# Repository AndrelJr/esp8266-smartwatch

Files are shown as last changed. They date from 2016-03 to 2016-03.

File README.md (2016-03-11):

# ESP8266 Smartwatch
## Pictures / Videos
Features overview
Side view
On a wrist

#### YouTube Videos
* [Building the watch](https://www.youtube.com/watch?v=ve8lzYSVnGo)
* [Minetest controller](https://www.youtube.com/watch?v=W3ALEUs_7kA)
* [Compass test](https://www.youtube.com/watch?v=Mj3a6peVI30)

# Hardware
## Specifications
* ESP8266 with 32Mbit of flash memory
* MPU-9250 gyroscope, accelerometer with integrated AK8963 magnetometer
* RV-3029-C2 Real Time Clock
* FT232RQ for USB communication
* SSD1306 OLED Display, 128x64
* 3 Hardware Buttons
* MCP73831 LiPo charger
* 250mAh LiPo battery
* Dimensions: 35 * 39 * 11mm
* WiFi with chip antenna
* Vibration Motor

See `board/v1/README.md` for a detailed parts list.

# Software
The firmwares in `firmwares` use the [esp-open-sdk](https://github.com/pfalcon/esp-open-sdk). You may need to customize the `main.c` files to reflect your WiFi configuration. This is mainly a hardware project and not a software project, so the firmwares are primarily meant to be demos for the hardware features of the watch. Firmwares can be uploaded using [esptool](https://github.com/themadinventor/esptool) and debugging is possible with a serial port terminal like [espterm](https://github.com/Jeija/espterm).

# Attribution
* `libesphttpd` (used in the minetest firmware) was [written by Spritetm](https://github.com/Spritetm/libesphttpd) and contributors and is licensed under "THE BEER-WARE LICENSE".
* `httpclient.c` / `httpclient.h` (included in all firmwares) was [written by Caerbannog](https://github.com/Caerbannog/esphttpclient) and contributors and is licensed under "THE BEER-WARE LICENSE".
* `i2c_master.h` / `i2c_master.c` was written by Espressif Systems

# License
The hardware design (schematic, PCB design, footprints, ...) is licensed under a [Creative Commons Attribution-NonCommercial-ShareAlike 4.0 International License](http://creativecommons.org/licenses/by-nc-sa/4.0/) (CC-BY-NC-SA).

The firmware source code is licensed under the [MIT License](https://opensource.org/licenses/MIT).

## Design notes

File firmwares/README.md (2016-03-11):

## Notice
While it would certainly be nice to have one firmware that supports all the features of the watch, I haven't had the time yet to write that. Technically it is absolutely possible, since the watch has a 32Mbit flash chip which is certainly more than enough for all of the different firmwares here. Also, I haven't published a firmware yet that uses all of the power-saving features of the ESP8266. `wifitime` uses light sleep mode and wakes up every 1 second to update the screen, which makes the battery last for about 1 day. With deep sleep and less frequent updates, battery life can easily reach 2 days.

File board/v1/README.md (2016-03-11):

# ESP8266 Smartwatch Hardware V1
## Parts list
* 1x PCB
* 1x ESP8266EX WiFi SoC
* 1x FT232RQ USB to UART
* 1x MCP73831 LiPo charger
* 1x TLV70233 SOT-23 LDO (or compatible)
* 1x W25Q32BV 32Mbit flash
* 1x InvenSense MPU-9250 9-axis sensor
* 1x RV-3029-C2 RTC
* 1x 26MHz crystal 2.5x2mm
* 1x Rainsun AN9520 Chip Antenna
* 3x TS-015A / WS-TUS 434331045822 Buttons
* 1x muRata BLM21PG 600 EMI Suppression Filter
* 1x USB Micro B connector, SMD
* 1x EastRising SSD1306 OLED
* 1x 250mAh LiPo
* 1x Low power vibration motor
* 1x BC849 SOT-23 NPN transistor
* 6x 100nF 0603 Capacitor
* 3x 10nF 0603 Capacitor
* 2x 4.7µF 0603 Capacitor
* 1x 100µF 1206 Capacitor
* 1x 10µF 1206 Capacitor
* 1x 5.6pF 0402 Capacitor
* 2x 10pF 0402 Capacitor
* 5x 1µF 0603 Capacitor
* 1x 2.2µF 0603 Capacitor
* 3x 1N4148 SOD-323 Diode
* 2x 1K 0603 Resistor
* 1x 12K 0603 Resistor
* 1x 3.3K 0603 Resistor
* 1x 300 0603 Resistor
* 1x 200 0603 Resistor
* 1x 330K 0603 Resistor
* 1x 100K 0603 Resistor
* 4x 10K 0603 Resistor
* 1x 50 0603 Resistor
* 1x 390K 0603 Resistor

## Production files
See the `gerber` directory for original PCB production files. My PCBs were manufactured by Seeedstudio's PCB service.

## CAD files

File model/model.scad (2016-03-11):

// All units in millimeters
handle_height = 2;
handle_outer_width = 31;
handle_inner_width = 27;
handle_distance = 2;
handle_conn_width = 3;

pcb_width = 35;
pcb_height = 30;
pcb_thickness = 1;

oled_offset_top = 3;
oled_nodisp_height = 4;
oled_disp_height = 15;
oled_width = 26.5;
oled_thickness = 2;

battery_width = 31.5;
battery_height = 20;
battery_thickness = 6;
battery_offset_left = 0;
battery_offset_bottom = 8;

button_height = 5;
button_width = 3.5;
button_thickness = 2;

button_knob_thickness = 1.4;
button_knob_height = 2.6;
button_knob_width = 1;

button1_offset_top =  2.5;
button2_offset_top = 12.5;
button3_offset_top = 22.5;

usbconn_width = 6.5;
usbconn_height = 8;
usbconn_thickness = 2.5;
usbconn_width_pcb = 4.5;
usbconn_offset_bottom = 1;

pcb_drillhole_offset_bottom = 3.5;
pcb_drillhole_offset_right = 14;
pcb_drillhole_diameter = 2;

module pcb_handle() {
	linear_extrude(height = pcb_thickness)  polygon(points=[
		[-handle_inner_width / 2, pcb_height / 2 + handle_distance],
		[handle_inner_width / 2, pcb_height / 2 + handle_distance],
		[handle_outer_width / 2, pcb_height / 2 + handle_distance + handle_height],
		[-handle_outer_width / 2, pcb_height / 2 + handle_distance + handle_height]
	]);

	linear_extrude(height = pcb_thickness)  polygon(points=[
		[-pcb_width / 2, pcb_height / 2],
		[-pcb_width / 2 + handle_conn_width, pcb_height / 2],
		[-handle_inner_width / 2, pcb_height / 2 + handle_distance],
		[-handle_outer_width / 2, pcb_height / 2 + handle_distance + handle_height]
	]);

	linear_extrude(height = pcb_thickness)  polygon(points=[
		[pcb_width / 2, pcb_height / 2],
		[pcb_width / 2 - handle_conn_width, pcb_height / 2],
		[handle_inner_width / 2, pcb_height / 2 + handle_distance],
		[handle_outer_width / 2, pcb_height / 2 + handle_distance + handle_height]
	]);
}

module pcb_drillhole() {
	translate([pcb_width / 2 - pcb_drillhole_offset_right,
			-pcb_height / 2 + pcb_drillhole_offset_bottom, 0]) {
		cylinder(h = pcb_thickness * 2, d1 = pcb_drillhole_diameter, $fn = 90, center = true);
	}
}

module pcb() {
	color([0, 0.6, 0, 1]) {
		difference() {
			translate([-pcb_width / 2, -pcb_height / 2, -pcb_thickness / 2]) {
				cube(size = [pcb_width, pcb_height, pcb_thickness]);
			}
			pcb_drillhole();
		}

		translate([0, 0, -pcb_thickness / 2]) {
			// Upper handle
			pcb_handle();

			// Lower handle
			mirror([0, 1, 0]) pcb_handle();
		}
	}
}

module oled() {
	translate([-oled_width / 2, pcb_height / 2 - oled_offset_top, pcb_thickness / 2]) {
		// Controller area
		color([0.5, 0.5, 0.5, 0.5]) {
			translate([0, -oled_nodisp_height, 0])
				cube(size = [oled_width, oled_nodisp_height, oled_thickness]);
		}

		// Display area
		color([0, 0, 0, 0.8]) {
			translate([0, -oled_nodisp_height - oled_disp_height, 0])
				cube(size = [oled_width, oled_disp_height, oled_thickness]);
		}
	}
}

module battery() {
	translate([-pcb_width / 2, -pcb_height / 2, -pcb_thickness / 2]) {
		translate([battery_offset_left, battery_offset_bottom, -battery_thickness]) {
			color([0.5, 0.5, 0.5, 1.0])
			cube(size = [battery_width, battery_height, battery_thickness]);
		}
	}
}

module button(offsetx, offsety) {
	translate([offsetx, offsety, -button_thickness - pcb_thickness / 2]) {
		color([0.7, 0.7, 0.7, 1.0]) {
			cube(size = [button_width, button_height, button_thickness]);
		}
	
		translate([button_width, button_height / 2 - button_knob_height / 2, 0]) {
			color([0.2, 0.2, 0.2, 1.0]) {
				cube(size = [button_knob_width, button_knob_height, button_knob_thickness]);
			}
		}
	}
}

module buttons() {
	button(pcb_width / 2 - button_width, pcb_height / 2 - button_height -  button1_offset_top);
	button(pcb_width / 2 - button_width, pcb_height / 2 - button_height -  button2_offset_top);
	button(pcb_width / 2 - button_width, pcb_height / 2 - button_height -  button3_offset_top);
}

module usbconn(offsetx, offsety) {
	translate([offsetx, offsety, -pcb_thickness / 2 - usbconn_thickness]) {
		color([0.3, 0.3, 0.3, 1.0]) {
			cube([usbconn_width, usbconn_height, usbconn_thickness]);
		}
	}
}

module connectors() {
	usbconn(-pcb_width / 2 - usbconn_width + usbconn_width_pcb, -pcb_height / 2 + usbconn_offset_bottom);
}

module watch(centerx, centery) {
	translate([centerx, centery]) {
		pcb();
		oled();
		battery();
		buttons();
		connectors();
	}
}

watch(0, 0);

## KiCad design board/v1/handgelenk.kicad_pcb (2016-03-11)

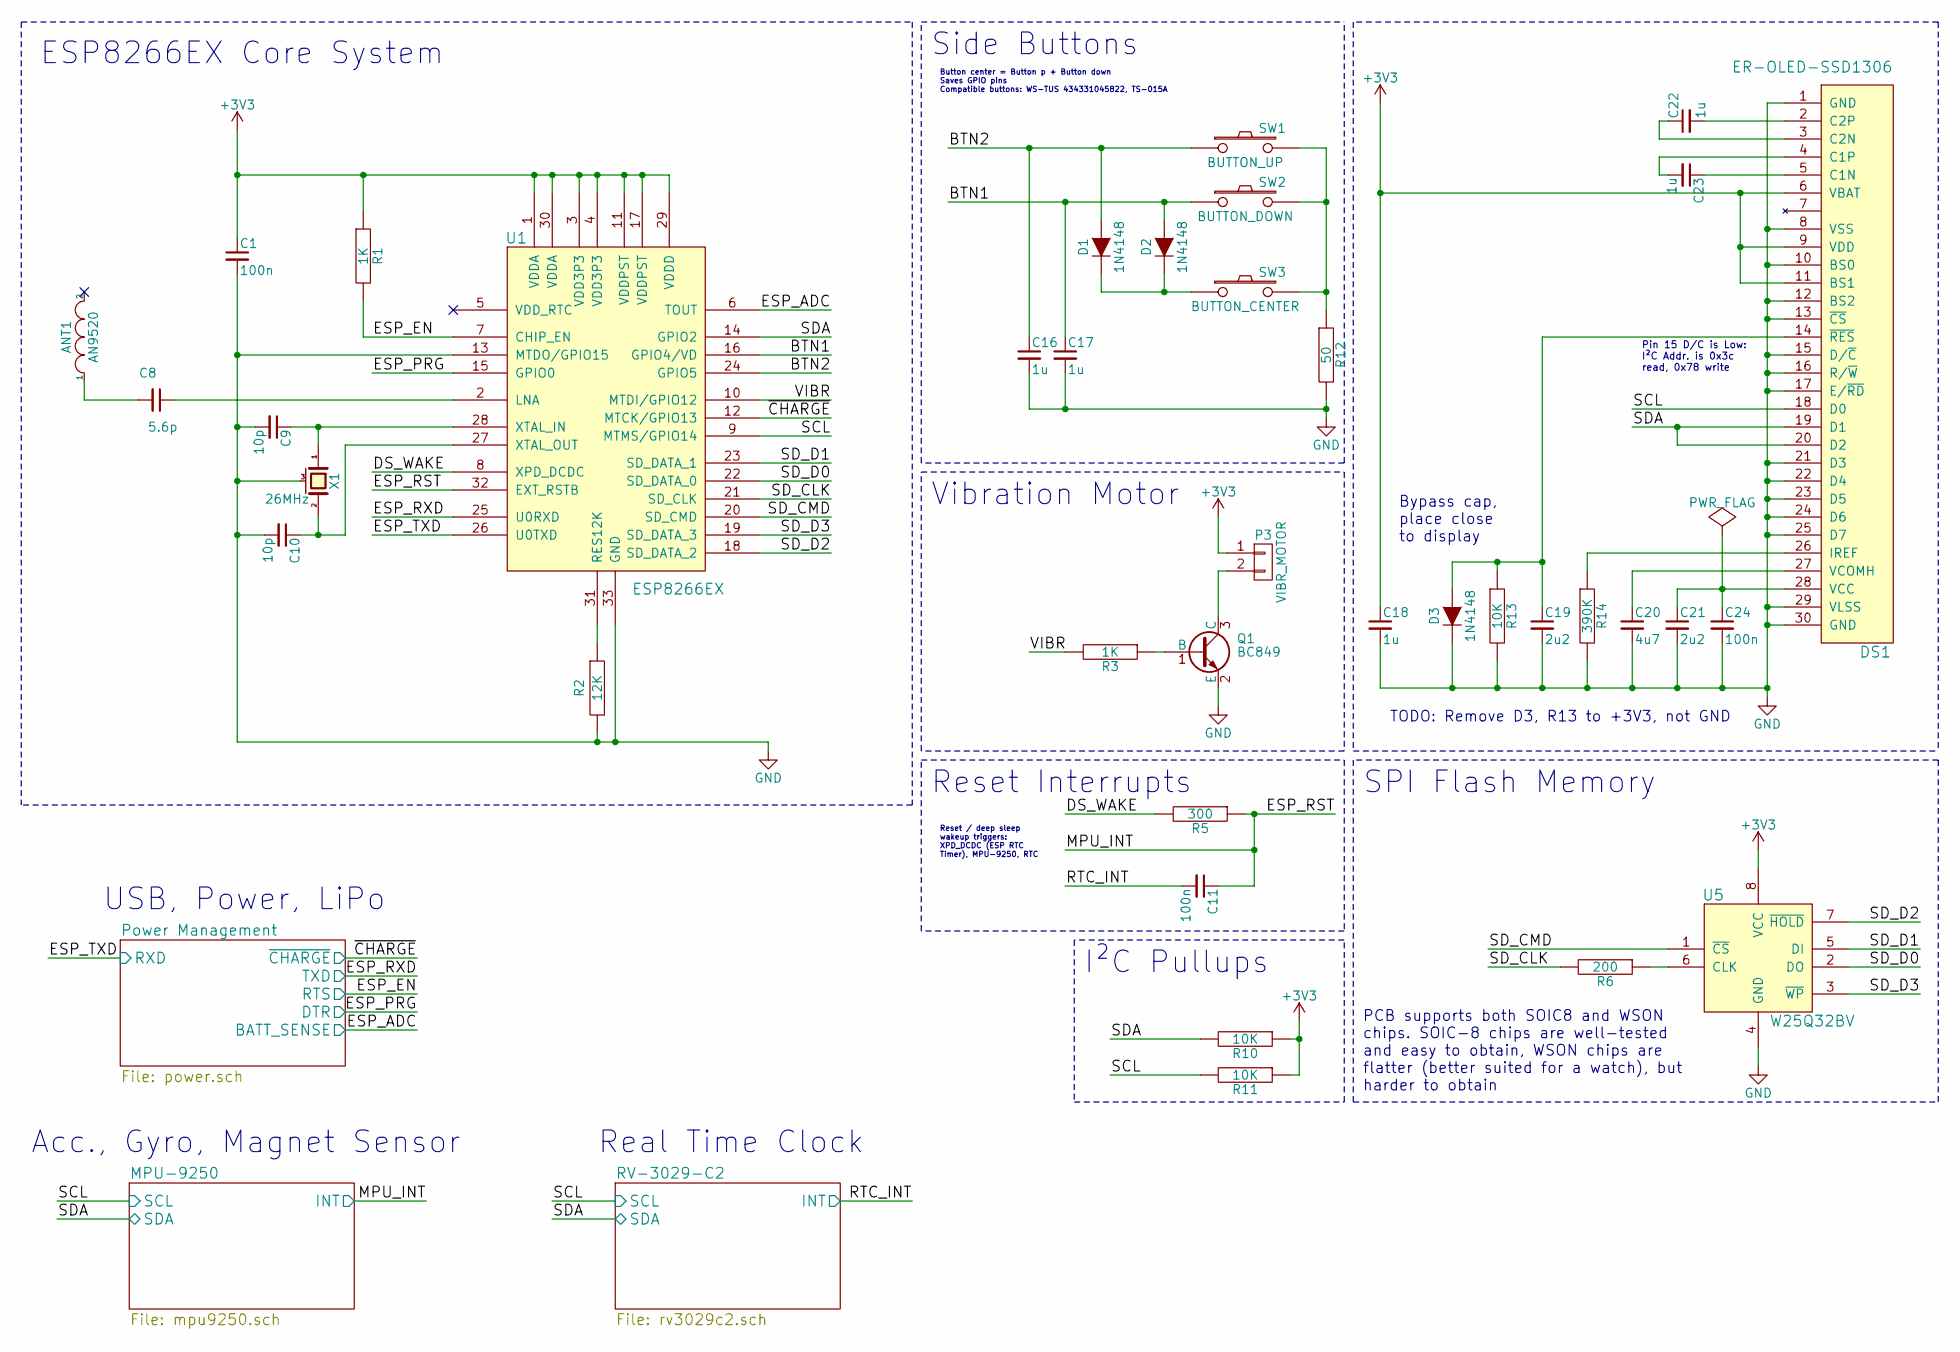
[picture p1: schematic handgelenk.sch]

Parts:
ANT1: AN9520; an9520
C1, C11, C24: 100n; C_0603
C8: 5.6p; C_0402
C9, C10: 10p; C_0402
C16, C17, C18, C22, C23: 1u; C_0603
C19, C21: 2u2; C_0603
C20: 4u7; C_0603
D1, D2, D3: 1N4148; SOD-323
DS1: ER-OLED-SSD1306; er-oled-ssd1306
P3: VIBR_MOTOR; Pin_Header_Straight_1x02
Q1: BC849; SOT-23
R1, R3: 1K; R_0603
R2: 12K; R_0603
R5: 300; R_0603
R6: 200; R_0603
R10, R11, R13: 10K; R_0603
R12: 50; R_0603
R14: 390K; R_0603
SW1: BUTTON_UP; ts015a
SW2: BUTTON_DOWN; ts015a
SW3: BUTTON_CENTER; ts015a
U1: ESP8266EX; QFN-32-1EP_5x5mm_Pitch0.5mm
U5: W25Q32BV; wson8_5x6
X1: 26MHz; crystal_2.5x2

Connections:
+3V3: C1.1, C18.1, DS1.6 (VBAT), DS1.9 (VDD), DS1.11 (BS1), P3.1, R1.1, R10.1, R11.1, U1.1 (VDDA), U1.3 (VDD3P3), U1.4 (VDD3P3), U1.11 (VDDPST), U1.17 (VDDPST), U1.29 (VDDD), U1.30 (VDDA), U5.8 (VCC); also elsewhere on the board
/BTN1: C17.1, D2.2 (A), SW2.1, U1.16 (GPIO4/VD)
/BTN2: C16.1, D1.2 (A), SW1.1, U1.24 (GPIO5)
/DS_WAKE: R5.2, U1.8 (XPD_DCDC)
/MPU-9250/INT: C11.1, R5.1, U1.32 (EXT_RSTB); also elsewhere on the board
/MPU-9250/SCL: DS1.18 (D0), R11.2, U1.9 (MTMS/GPIO14); also elsewhere on the board
/MPU-9250/SDA: DS1.19 (D1), DS1.20 (D2), R10.2, U1.14 (GPIO2); also elsewhere on the board
/Power Management/BATT_SENSE: U1.6 (TOUT); also elsewhere on the board
/Power Management/DTR: U1.15 (GPIO0); also elsewhere on the board
/Power Management/RTS: R1.2, U1.7 (CHIP_EN); also elsewhere on the board
/Power Management/RXD: U1.26 (U0TXD); also elsewhere on the board
/Power Management/TXD: U1.25 (U0RXD); also elsewhere on the board
/Power Management/~CHARGE: U1.12 (MTCK/GPIO13); also elsewhere on the board
/RV-3029-C2/INT: C11.2; also elsewhere on the board
/SD_CLK: R6.2, U1.21 (SD_CLK)
/SD_CMD: U1.20 (SD_CMD), U5.1 (~CS)
/SD_D0: U1.22 (SD_DATA_0), U5.2 (DO)
/SD_D1: U1.23 (SD_DATA_1), U5.5 (DI)
/SD_D2: U1.18 (SD_DATA_2), U5.7 (~HOLD)
/SD_D3: U1.19 (SD_DATA_3), U5.3 (~WP)
/VIBR: R3.2, U1.10 (MTDI/GPIO12)
GND: C1.2, C9.2, C10.2, C16.2, C17.2, C18.2, C19.2, C20.2, C21.2, C24.2, D3.1 (K), DS1.1 (GND), DS1.8 (VSS), DS1.10 (BS0), DS1.12 (BS2), DS1.13 (~CS), DS1.15 (D/~C), DS1.16 (R/~W), DS1.17 (E/~RD), DS1.21 (D3), DS1.22 (D4), DS1.23 (D5), DS1.24 (D6), DS1.25 (D7), DS1.29 (VLSS), DS1.30 (GND), Q1.2 (E), R2.2, R12.2, R13.2, R14.2, U1.13 (MTDO/GPIO15), U1.33 (GND), U5.4 (GND), X1.3 (case); also elsewhere on the board
unnamed: ANT1.1, C8.2
unnamed: C8.1, U1.2 (LNA)
unnamed: C9.1, U1.28 (XTAL_IN), X1.1
unnamed: C10.1, U1.27 (XTAL_OUT), X1.2
unnamed: C19.1, D3.2 (A), DS1.14 (~RES), R13.1
unnamed: C20.1, DS1.27 (VCOMH)
unnamed: C21.1, C24.1, DS1.28 (VCC)
unnamed: C22.1, DS1.3 (C2N)
unnamed: C22.2, DS1.2 (C2P)
unnamed: C23.1, DS1.5 (C1N)
unnamed: C23.2, DS1.4 (C1P)
unnamed: D1.1 (K), D2.1 (K), SW3.1
unnamed: DS1.26 (IREF), R14.1
unnamed: P3.2, Q1.3 (C)
unnamed: Q1.1 (B), R3.1
unnamed: R2.1, U1.31 (RES12K)
unnamed: R6.1, U5.6 (CLK)
unnamed: R12.1, SW1.2, SW2.2, SW3.2

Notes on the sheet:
Reset / deep sleep wakeup triggers: XPD_DCDC (ESP RTC Timer), MPU-9250, RTC
PCB supports both SOIC8 and WSON chips. SOIC-8 chips are well-tested and easy to obtain, WSON chips are flatter (better suited for a watch), but harder to obtain
SPI Flash Memory
Pin 15 D/C is Low: I²C Addr. is 0x3c read, 0x78 write
Bypass cap, place close to display
Button center = Button p + Button down Saves GPIO pins Compatible buttons: WS-TUS 434331045822, TS-015A
Side Buttons
Vibration Motor
ESP8266EX Core System
I²C Pullups
Reset Interrupts
Acc., Gyro, Magnet Sensor
Real Time Clock
USB, Power, LiPo
TODO: Remove D3, R13 to +3V3, not GND

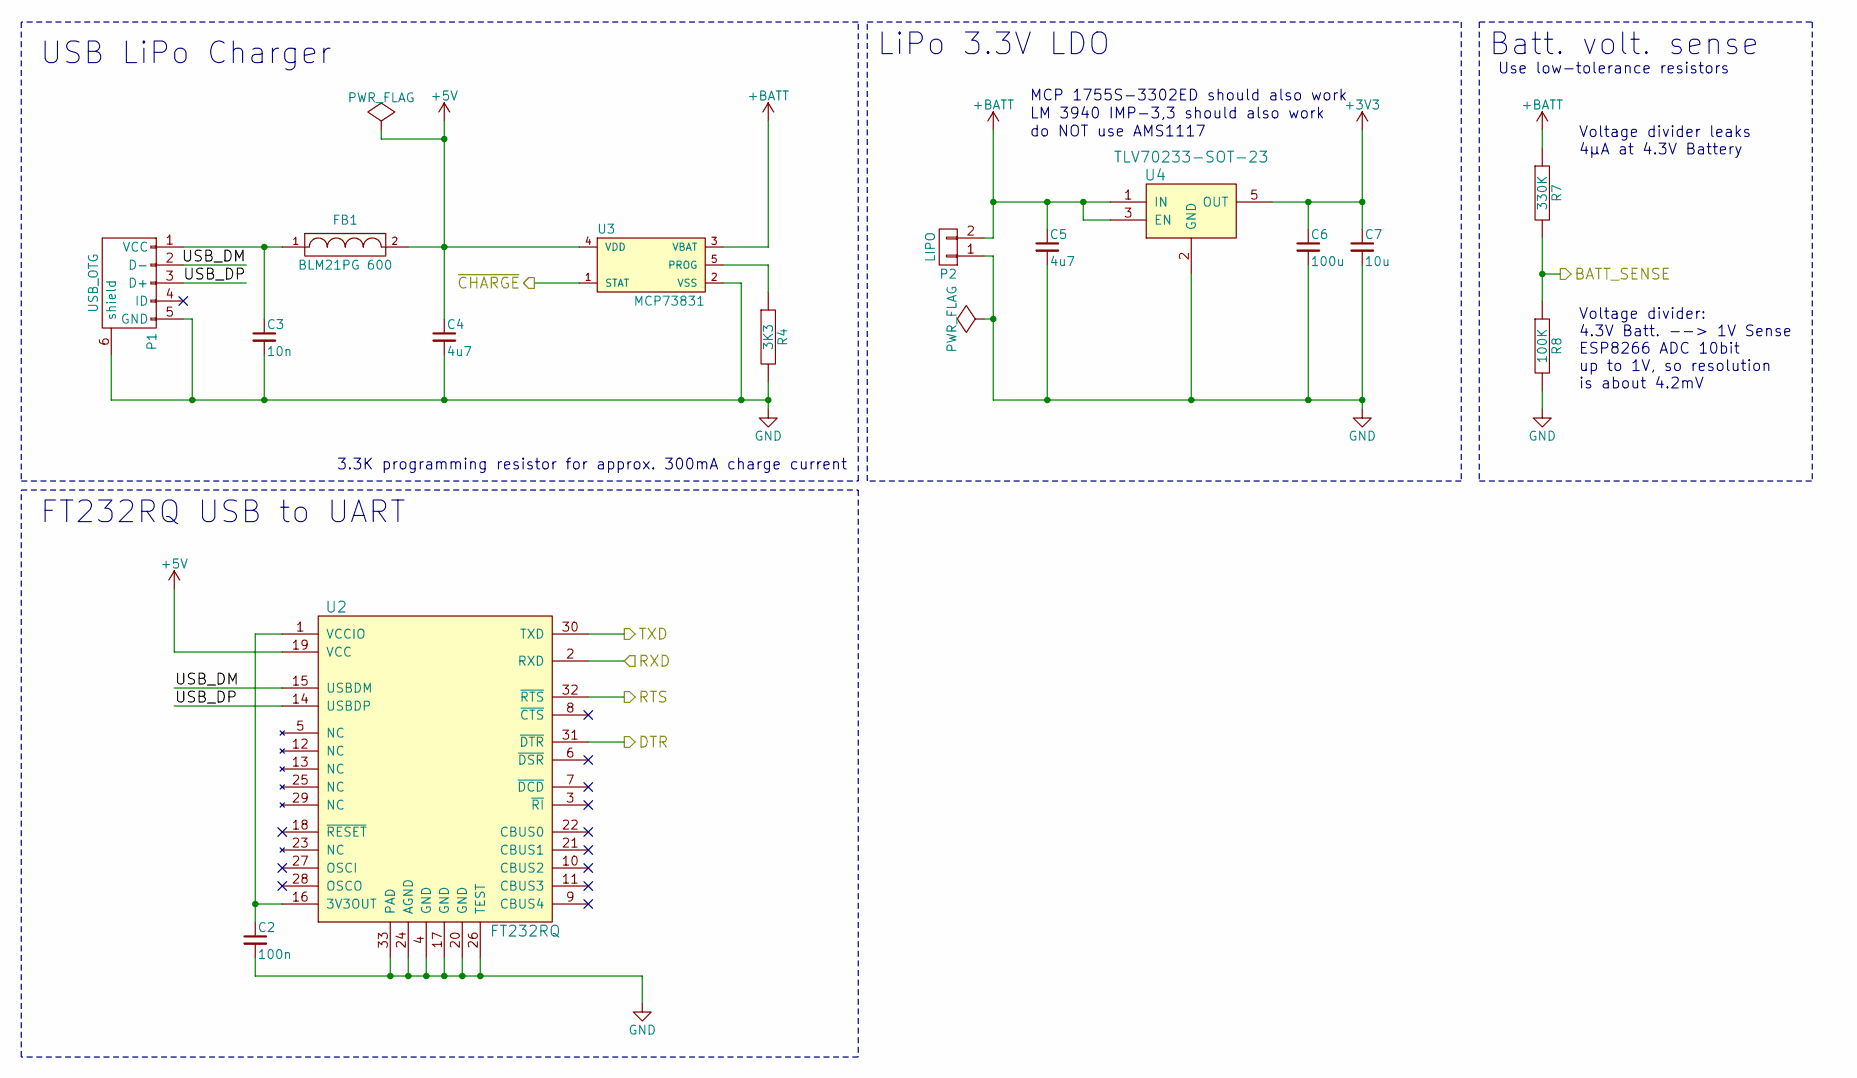
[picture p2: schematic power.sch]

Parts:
C2: 100n; C_0603
C3: 10n; C_0603
C4, C5: 4u7; C_0603
C6: 100u; C_1206
C7: 10u; C_0603
FB1: BLM21PG 600; C_0805
P1: USB_OTG; USB_Micro-B
P2: LIPO; Pin_Header_Straight_1x02
R4: 3K3; R_0603
R7: 330K; R_0603
R8: 100K; R_0603
U2: FT232RQ; QFN-32-1EP_5x5mm_Pitch0.5mm
U3: MCP73831; SOT-23-5
U4: TLV70233-SOT-23; SOT-23-5

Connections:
+3V3: C6.1, C7.1, U4.5 (OUT); also elsewhere on the board
+5V: C4.1, FB1.2, U2.19 (VCC), U3.4 (VDD)
+BATT: C5.1, P2.2, R7.1, U3.3 (VBAT), U4.1 (IN), U4.3 (EN)
/Power Management/BATT_SENSE: R7.2, R8.1; also elsewhere on the board
/Power Management/DTR: U2.31 (~DTR); also elsewhere on the board
/Power Management/RTS: U2.32 (~RTS); also elsewhere on the board
/Power Management/RXD: U2.2 (RXD); also elsewhere on the board
/Power Management/TXD: U2.30 (TXD); also elsewhere on the board
/Power Management/USB_DM: P1.2 (D-), U2.15 (USBDM)
/Power Management/USB_DP: P1.3 (D+), U2.14 (USBDP)
/Power Management/~CHARGE: U3.1 (STAT); also elsewhere on the board
GND: C2.2, C3.2, C4.2, C5.2, C6.2, C7.2, P1.5 (GND), P1.6 (shield), P2.1, R4.2, R8.2, U2.4 (GND), U2.17 (GND), U2.20 (GND), U2.24 (AGND), U2.26 (TEST), U2.33 (PAD), U3.2 (VSS), U4.2 (GND); also elsewhere on the board
unnamed: C2.1, U2.1 (VCCIO), U2.16 (3V3OUT)
unnamed: C3.1, FB1.1, P1.1 (VCC)
unnamed: R4.1, U3.5 (PROG)

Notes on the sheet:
do NOT use AMS1117
LM 3940 IMP-3,3 should also work
MCP 1755S-3302ED should also work
3.3K programming resistor for approx. 300mA charge current
LiPo 3.3V LDO
USB LiPo Charger
FT232RQ USB to UART
Batt. volt. sense
Use low-tolerance resistors
Voltage divider: 4.3V Batt. --> 1V Sense ESP8266 ADC 10bit up to 1V, so resolution is about 4.2mV
Voltage divider leaks 4µA at 4.3V Battery

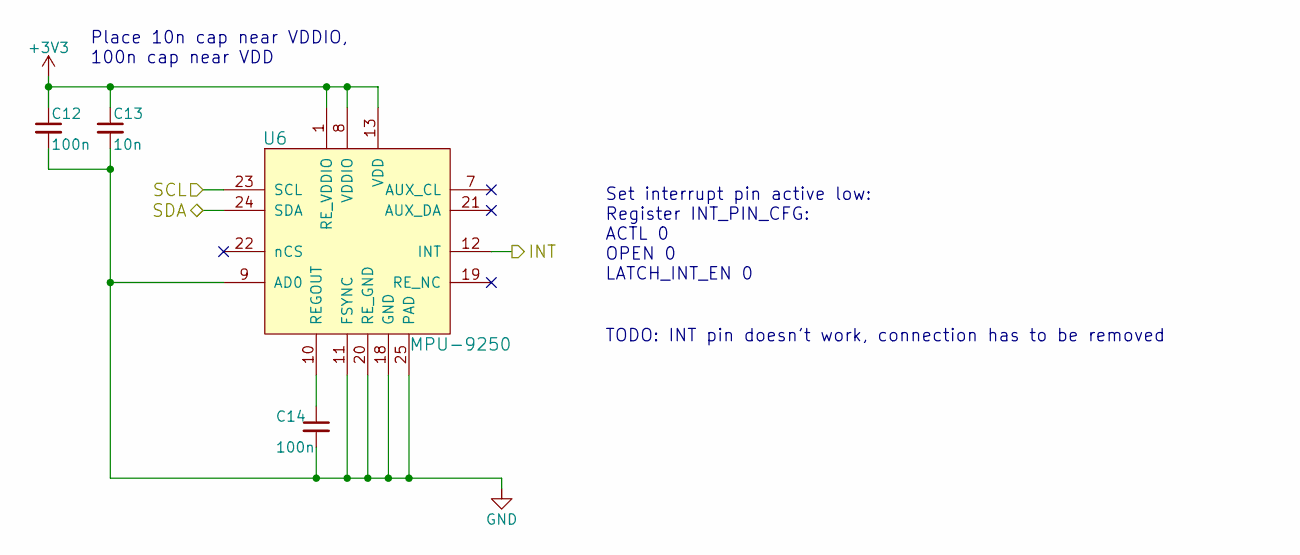
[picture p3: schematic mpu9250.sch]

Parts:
C12, C14: 100n; C_0603
C13: 10n; C_0603
U6: MPU-9250; QFN-24-1EP_3x3mm_Pitch0.4mm

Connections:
+3V3: C12.1, C13.1, U6.1 (RE_VDDIO), U6.8 (VDDIO), U6.13 (VDD); also elsewhere on the board
/MPU-9250/INT: U6.12 (INT); also elsewhere on the board
/MPU-9250/SCL: U6.23 (SCL); also elsewhere on the board
/MPU-9250/SDA: U6.24 (SDA); also elsewhere on the board
GND: C12.2, C13.2, C14.2, U6.9 (AD0), U6.11 (FSYNC), U6.18 (GND), U6.20 (RE_GND), U6.25 (PAD); also elsewhere on the board
unnamed: C14.1, U6.10 (REGOUT)

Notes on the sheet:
Place 10n cap near VDDIO, 100n cap near VDD
Set interrupt pin active low: Register INT_PIN_CFG: ACTL 0 OPEN 0 LATCH_INT_EN 0
TODO: INT pin doesn't work, connection has to be removed

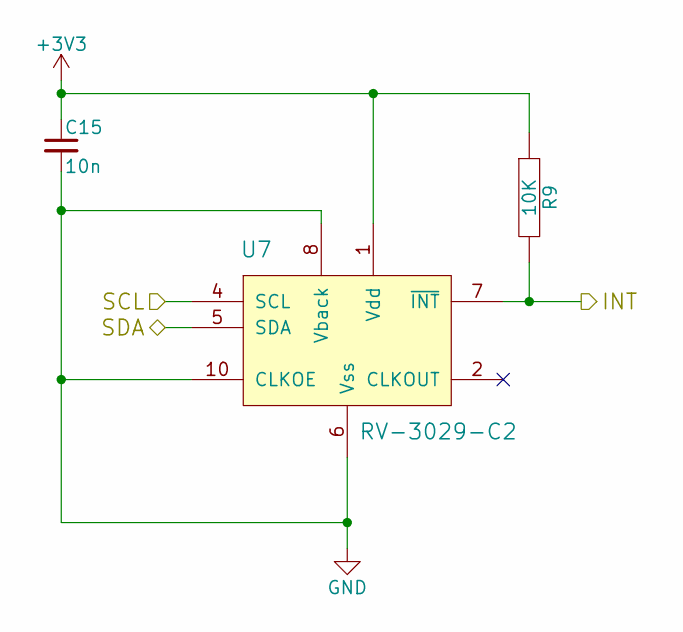
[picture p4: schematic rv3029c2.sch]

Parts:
C15: 10n; C_0603
R9: 10K; R_0603
U7: RV-3029-C2; rv3029

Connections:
+3V3: C15.1, R9.1, U7.1 (Vdd); also elsewhere on the board
/MPU-9250/SCL: U7.4 (SCL); also elsewhere on the board
/MPU-9250/SDA: U7.5 (SDA); also elsewhere on the board
/RV-3029-C2/INT: R9.2, U7.7 (~INT); also elsewhere on the board
GND: C15.2, U7.6 (Vss), U7.8 (Vback), U7.10 (CLKOE); also elsewhere on the board

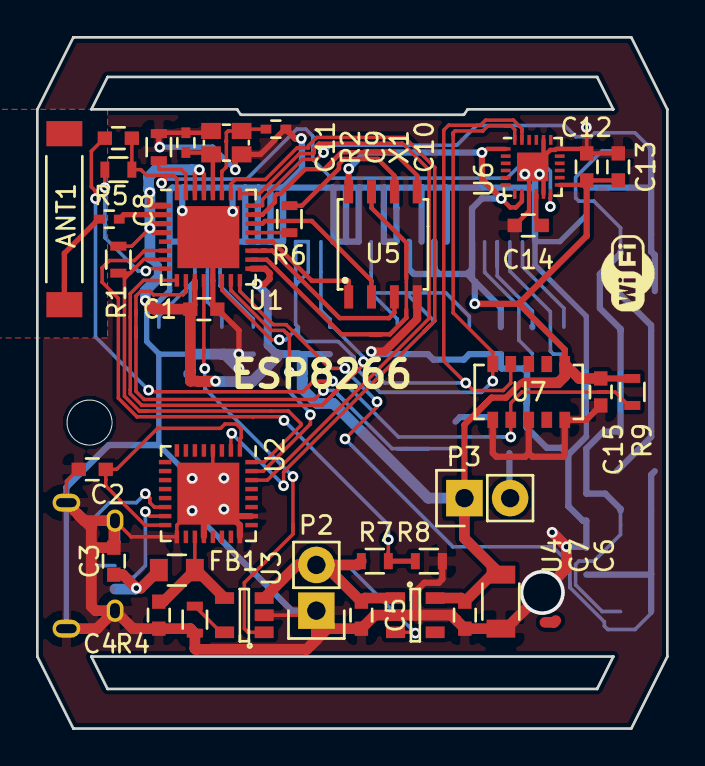
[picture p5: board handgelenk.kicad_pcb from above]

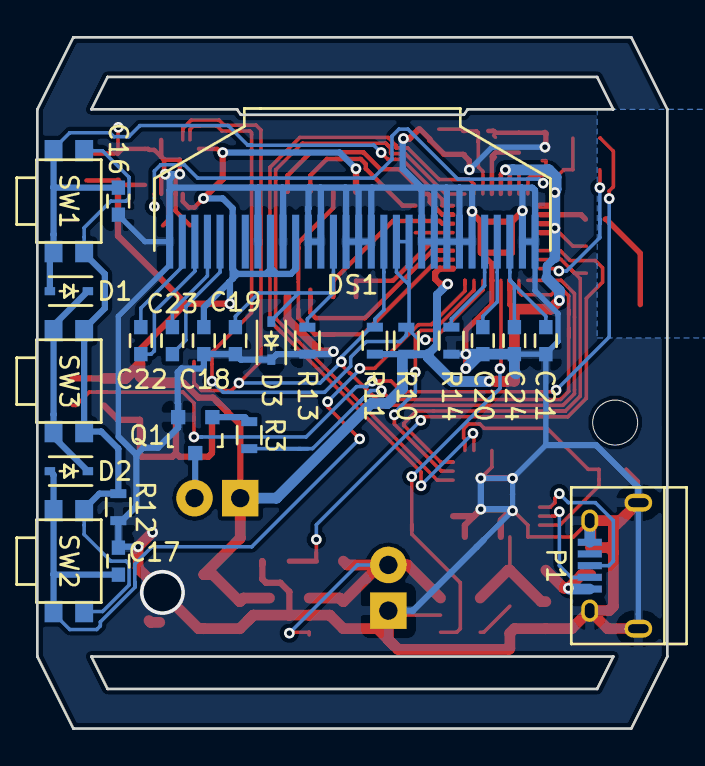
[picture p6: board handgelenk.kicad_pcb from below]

Board: 2 copper layers, 35.0 x 38.4 mm, 59 parts (24 on the bottom side), 48 nets.

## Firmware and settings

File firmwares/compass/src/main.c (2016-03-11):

// System
#include <user_interface.h>
#include <math.h>
#include <os_type.h>
#include <ets_sys.h>
#include <osapi.h>
#include <gpio.h>

// Configuration
#include "user_config.h"

// Project
#include "httpclient.h"
#include "i2c_master.h"
#include "buttons.h"
#include "mpu9250.h"
#include "ssd1306.h"
#include "rv3029.h"
#include "vector.h"
#include "util.h"

os_timer_t magnet_timer;
vec3f calib_bias;

#define COMPASS_CENTER_X 32
#define COMPASS_CENTER_Y 32
#define COMPASS_RADIUS 30
void ICACHE_FLASH_ATTR compass_draw(float angle) {
	float a;
	ssd1306_setpixel(COMPASS_CENTER_X, COMPASS_CENTER_Y, true);
	ssd1306_setpixel(COMPASS_CENTER_X + 1, COMPASS_CENTER_Y, true);
	ssd1306_setpixel(COMPASS_CENTER_X, COMPASS_CENTER_Y + 1, true);
	ssd1306_setpixel(COMPASS_CENTER_X - 1, COMPASS_CENTER_Y, true);
	ssd1306_setpixel(COMPASS_CENTER_X, COMPASS_CENTER_Y - 1, true);

	for (a = angle; a < angle + 2 * PI; a += PI / 8) {
		float startx =  ((a == angle) ? COMPASS_RADIUS - 15 : COMPASS_RADIUS - 5) * sin(a) + COMPASS_CENTER_X;
		float starty = -((a == angle) ? COMPASS_RADIUS - 15 : COMPASS_RADIUS - 5) * cos(a) + COMPASS_CENTER_Y;
		float endx =  COMPASS_RADIUS * sin(a) + COMPASS_CENTER_X;
		float endy = -COMPASS_RADIUS * cos(a) + COMPASS_CENTER_Y;
		if (a == angle)
			ssd1306_text_small(startx - 3 - (endx - startx) / 2, starty - 4 - (endy - starty) / 2, "N");
		ssd1306_line(startx, starty, endx, endy, true);
	}
}

void ICACHE_FLASH_ATTR magnet_timer_cb() {
	vec3s16 field;
	ak8963_get_field(&field);
	field.x -= calib_bias.x;
	field.y -= calib_bias.y;
	field.z -= calib_bias.z;
	//os_printf("Measurement: { x = %d, y = %d, z = %d }\r\n", (int16_t)(field.x), (int16_t)(field.y), (int16_t)(field.z));
	angles2f north = vec3s16_to_angles2f(field);
	//os_printf("North: { yaw = %d, pitch = %d }\r\n", (int16_t)(north.yaw * 180 / PI), (int16_t)(north.pitch * 180 / PI));
	ak8963_set_opmode(AK8963_SINGLE, AK8963_16BIT);

	ssd1306_clear();
	compass_draw(north.yaw);
	ssd1306_line(70, 0, 70, 63, true);
	ssd1306_text_small(75, 24, "Inclin.:");
	char incdeg[6];
	os_sprintf(incdeg, "%d°", (int16_t)(north.pitch * 180 / PI));
	ssd1306_text_small(75, 32, incdeg);
	ssd1306_flip();
}

void ICACHE_FLASH_ATTR on_ak8963_calibration(vec3f bias) {
	os_printf("Bias: { x = %d, y = %d, z = %d }\r\n", (int16_t)bias.x, (int16_t)bias.y, (int16_t)bias.z);
	calib_bias.x = bias.x;
	calib_bias.y = bias.y;
	calib_bias.z = bias.z;

	/*** WiFi sleep ***/
	wifi_station_disconnect();
	wifi_set_opmode(NULL_MODE);
	wifi_fpm_set_sleep_type(MODEM_SLEEP_T);
	wifi_fpm_open();
	wifi_fpm_do_sleep(0xfffffff);

	os_timer_setfn(&magnet_timer, (os_timer_func_t *)magnet_timer_cb, NULL);
	os_timer_arm(&magnet_timer, 300, true);
}

void ICACHE_FLASH_ATTR user_init(void) {
	uart_div_modify(0, UART_CLK_FREQ / BAUD);

	wifi_set_opmode(STATION_MODE);
	wifi_station_connect();

	/*** I²C init ***/
	i2c_master_gpio_init();
	mpu9250_init();
	ak8963_init();

	os_delay_us(10000);
	i2c_scanbus();

	/*** LCD Init ***/
	ssd1306_init(0);
	ssd1306_text_small(10, 10, "Init...");
	ssd1306_flip();

	// ~Charge input
	PIN_FUNC_SELECT(PERIPHS_IO_MUX_MTCK_U, FUNC_GPIO13);
	gpio_output_set(0, 0, 0, BIT13);

	// Button inputs
	buttons_init();

	ak8963_calibration_start(10000, on_ak8963_calibration);

	os_printf("Startup\r\n");
}

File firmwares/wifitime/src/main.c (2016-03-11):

// System
#include <ets_sys.h>
#include <osapi.h>
#include <gpio.h>
#include <os_type.h>
#include <user_interface.h>

// Configuration
#include "user_config.h"

// Project
#include "i2c_master.h"
#include "ssd1306.h"
#include "rv3029.h"
#include "httpclient.h"

os_timer_t oled_refresh;
os_timer_t time_refresh;

bool scanning = false;

os_timer_t resume_timer;
void ICACHE_FLASH_ATTR resume_cb() {
	scanning = false;
}

void ICACHE_FLASH_ATTR scan_done(void *arg, STATUS status) {
	char ssid[33];
	ssd1306_fill(0x00);
	if (status == OK) {
		struct bss_info *bss_link = (struct bss_info *)arg;

		uint8_t i = 0;
		while (bss_link != NULL && i < 8) {
			os_memcpy(ssid, bss_link->ssid, os_strlen(bss_link->ssid));
			ssid[os_strlen(bss_link->ssid)] = 0x00;

			os_printf("> %s\r\n", ssid);
			ssd1306_text_small(0, i * 8, ssid);

			bss_link = bss_link->next.stqe_next;
			i++;
		}
	}

	os_timer_setfn(&resume_timer, (os_timer_func_t *)resume_cb, NULL);
	os_timer_arm(&resume_timer, 4000, 0);
	ssd1306_flip();
}

void ICACHE_FLASH_ATTR wifi_scan(void) {
	scanning = true;
	ssd1306_fill(0x00);
	ssd1306_text_large(20, 10, "Scanning...");
	ssd1306_flip();
	wifi_station_scan(NULL, scan_done);
}

void ICACHE_FLASH_ATTR oled_refresh_cb(void) {
	// Button status
	// if (!GPIO_INPUT_GET(4) && !GPIO_INPUT_GET(5)) wifi_scan();

	if (scanning) return;
	ssd1306_fill(0x00);

	struct TimeSpec time;
	rv3029_gettime(&time);
	char timestring[20];
	os_sprintf(timestring, "%2d:%02d:%02d", time.hours, time.minutes, time.seconds);
	ssd1306_text_large(32, 15, timestring);

	char datestring[20];
	os_sprintf(datestring, "%d-%02d-%02d", 2000 + time.years, time.months, time.date);
	ssd1306_text_small(34, 31, datestring);

	if (!GPIO_INPUT_GET(4)) {
		char voltline[10];
		float batt_volt = ((float)system_adc_read()) * (VOLT_DIV_DOWN + VOLT_DIV_UP) / VOLT_DIV_DOWN / 1024;
		os_sprintf(voltline, "%d.%02d V", (uint16_t)batt_volt, ((uint16_t)(batt_volt * 100)) % 100);
		ssd1306_text_small(46, 50, voltline);
	}

	ssd1306_flip();
}

void ICACHE_FLASH_ATTR http_callback_time(char *res, int status, char *res_full)
{
	if (status == HTTP_STATUS_GENERIC_ERROR) return;

	// Send "ESP" string in request to make sure the API actually answered the request
	if (res[0] == 'E' && res[1] == 'S' && res[2] == 'P') {
		// Split res by inserting NUL-termination characters between numbers
		uint8_t i = 0;
		while (res[i] != 0x00) {
			if (res[i] == ' ') res[i] = 0x00;
			i++;
		}

		struct TimeSpec settime;
		settime.years = atoi(res + 4);
		settime.months = atoi(res + 7);
		settime.date = atoi(res + 10);
		settime.dow = atoi(res + 13);
		settime.hours = atoi(res + 15);
		settime.minutes = atoi(res + 18);
		settime.seconds = atoi(res + 21);

		rv3029_settime(&settime);

		/*** WiFi sleep ***/
		wifi_station_disconnect();
		wifi_set_opmode(NULL_MODE);
		wifi_fpm_set_sleep_type(MODEM_SLEEP_T);
		wifi_fpm_open();
		wifi_fpm_do_sleep(0xfffffff);
	}
}

void ICACHE_FLASH_ATTR time_refresh_cb(void) {
	// year month date dow hours minutes seconds
	http_get("http://www.timeapi.org/cet?ESP%20\\y%20\\m%20\\d%20\\u%20\\H%20\\M%20\\S", "", http_callback_time);
}

void ICACHE_FLASH_ATTR user_init(void) {
	uart_div_modify(0, UART_CLK_FREQ / BAUD);

	// LCD Init
	i2c_master_gpio_init();
	i2c_scanbus();
	ssd1306_init(0);

	// ~Charge input
	PIN_FUNC_SELECT(PERIPHS_IO_MUX_MTCK_U, FUNC_GPIO13);
	gpio_output_set(0, 0, 0, BIT13);

	// Button inputs
	PIN_FUNC_SELECT(PERIPHS_IO_MUX_GPIO4_U, FUNC_GPIO4);
	PIN_FUNC_SELECT(PERIPHS_IO_MUX_GPIO5_U, FUNC_GPIO5);
	gpio_output_set(0, 0, 0, BIT4);
	gpio_output_set(0, 0, 0, BIT5);
	PIN_PULLUP_EN(PERIPHS_IO_MUX_GPIO4_U);
	PIN_PULLUP_EN(PERIPHS_IO_MUX_GPIO5_U);

	// Setup Wifi
	wifi_set_opmode(STATION_MODE);

	// No need for a Password in the German "Freifunk" Network ;)
	char ssid[32] = "Freifunk";
	char pass[64] = "";
	struct station_config sta_conf;
	sta_conf.bssid_set = 0;   
    os_memcpy(&sta_conf.ssid, ssid, 32);
    os_memcpy(&sta_conf.password, pass, 64);

    wifi_station_set_config(&sta_conf);
	wifi_station_connect();

	//struct TimeSpec time;
	//rv3029_gettime(&time);
	//os_printf("Time: %d-%d-%d %d:%d:%d\r\n", 2000 + time.years, time.months, time.date, time.hours, time.minutes, time.seconds);

	os_printf("Startup\r\n");

	// Timers
	os_timer_setfn(&oled_refresh, (os_timer_func_t *)oled_refresh_cb, NULL);
	os_timer_arm(&oled_refresh, 1000, 1);

	os_timer_setfn(&time_refresh, (os_timer_func_t *)time_refresh_cb, NULL);
	os_timer_arm(&time_refresh, 120000, 1);
}
